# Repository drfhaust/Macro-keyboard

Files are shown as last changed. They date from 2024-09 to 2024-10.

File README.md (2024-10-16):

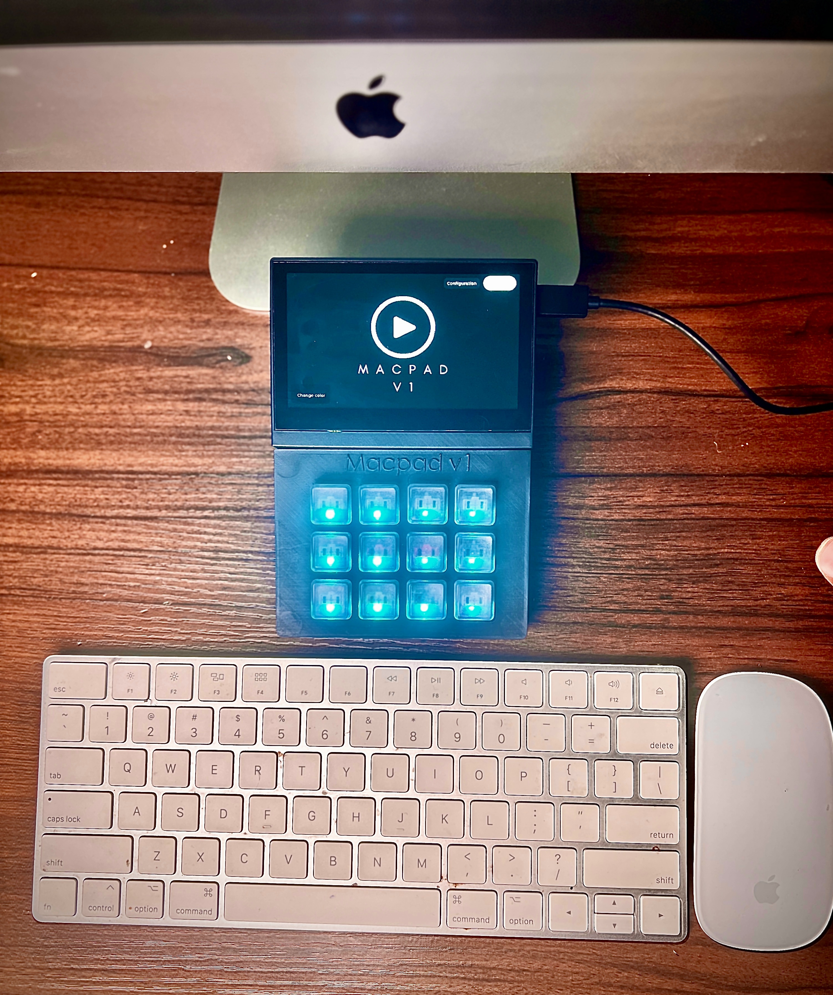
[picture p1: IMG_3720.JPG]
image of the macro keyboard

# Macro Keyboard

**Macro Keyboard with ESP32-S3**

This repository contains the design and code for building a custom macro keyboard powered by the ESP32-S3 microcontroller.

## Overview

- **Design**: A macro keyboard with customizable keys and LEDs for different functionalities.
- **Microcontroller**: Powered by the ESP32-S3 with a built-in touch screen and additional hardware components.
- **Customization**: Supports custom key mappings and macros via a JSON configuration.
- **Hardware Design**: The keyboard's hardware is modular, making it adaptable for various input needs.

## Hardware Specifications

- **Microcontroller**: ESP32-S3 with built-in wireless connectivity.
- **Key Components**: Uses Cherry MX-compatible key switches.
- **LEDs**: Individually addressable RGB LEDs for customizable lighting.
- **Screen**: Touch-enabled screen for additional control and feedback.
- **Battery**: Supports external power, and can be adapted for battery-powered use.
- **Charging**: USB Type-C port for charging and data transfer.
- **Connection**: Supports both wired and wireless communication with a host device.

## Software Features

- **Macro Management**: The macros can be configured through the `button.json` file, where each button is assigned a specific action or macro.
- **LED Control**: RGB LEDs can be customized for each button based on the configuration.
- **Key Mapping**: Easily programmable for various applications, from simple shortcuts to complex multi-step macros.
- **Python Integration**: Python scripts are provided to manage macro configurations and interface with the hardware.

## Power Details

- **Power Input**: Powered through USB Type-C or battery.
- **Power Consumption**: Optimized for low power consumption during idle states.

## Repository Structure

- **Arduino code**: Contains the LVGL porting for the ESP32-S3 along with the Arduino source code for the project.
  - `lvgl_Porting`: Core source files for integrating LVGL (LittlevGL) with the ESP32-S3.
  
- **Macro keyboard**: Includes hardware designs, PCB schematics, and component configurations.
  - `GERBER`: Files for manufacturing the PCB.
  - `custom components`: KiCad components for custom parts used in the keyboard.
  - `backups`: Backup files for the PCB designs.

- **python code**: Python scripts to manage macros and configure button functionalities.
  - `macro_manager_v4.py`: Python script for managing the macro functions of the keyboard.
  
- **solidwork 3d**: 3D models of the keyboard parts, including key switches and case designs.
  
- **button.json**: Configuration file where button mappings and LED colors are stored.

## Getting Started

1. **Clone this repository**:
   ```bash
   git clone <repository-url>
   ```

2. **Hardware Setup**: 
   - Flash the ESP32-S3 with the code in `Arduino code/lvgl_Porting`.
   - Assemble the PCB and components according to the schematics in the `Macro keyboard` folder.

3. **Software Setup**:
   - Install the required Python libraries by running:
     ```bash
     pip install -r requirements.txt
     ```

4. **Macro Management**:
   - Configure macros by editing `button.json`.
   - Run the macro manager script to apply your changes:
     ```bash
     python python code/v4/macro_manager_v4.py
     ```

## Contributing

Please read the contribution guidelines before making any changes.

## License

This project is licensed under the MIT License.

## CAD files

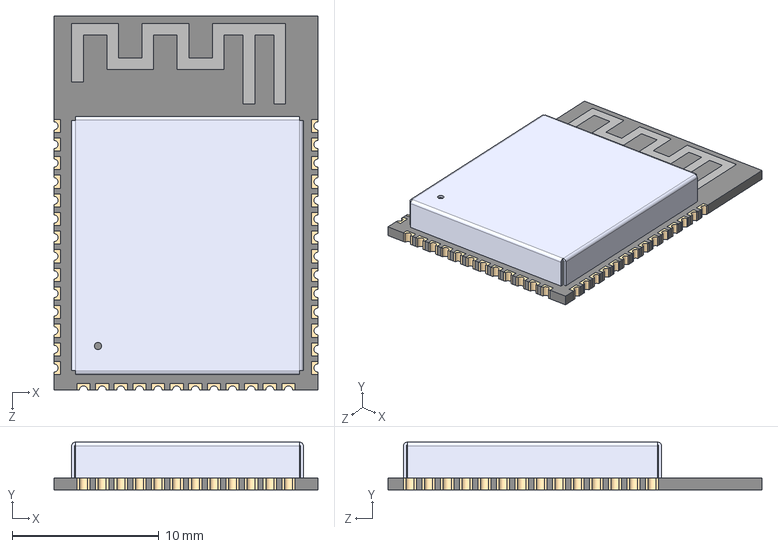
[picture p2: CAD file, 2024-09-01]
macro mech keyboard/custom components/ESP32-S3-WROOM-1-N8R8.step
18.0 x 3.25 x 25.5 mm

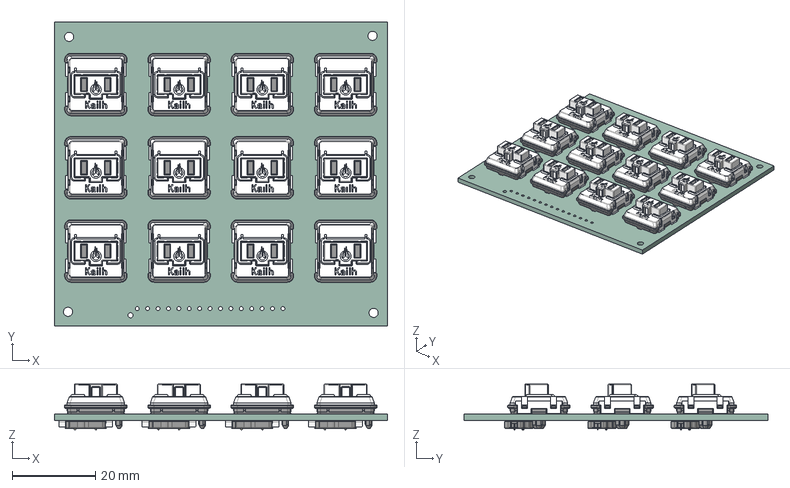
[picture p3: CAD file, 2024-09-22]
macro mech keyboard/Macro keyboard.step
80.0 x 73.1 x 11.0 mm
C_0603_1608Metric x 12
kailh CPG135001D03 x 12
PG1350 x 12
Macro keyboard_PCB

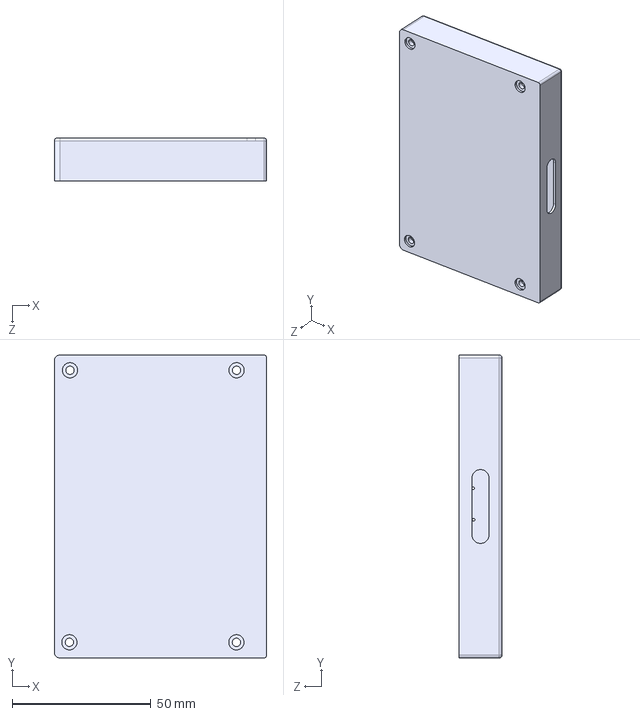
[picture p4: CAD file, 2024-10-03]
solidwork 3d/SCREEN BEZEL.STEP
76.5 x 109.2 x 15.5 mm

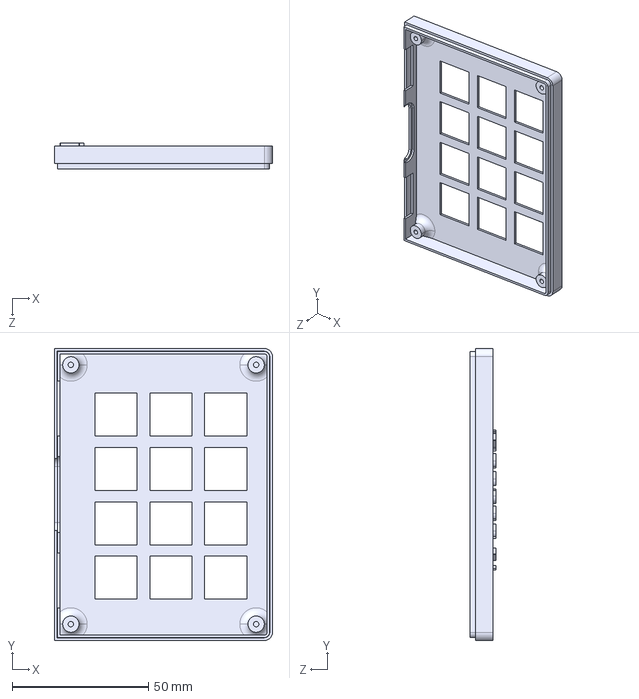
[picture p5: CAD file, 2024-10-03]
solidwork 3d/key top.STEP
80.0 x 107.2 x 9.50 mm

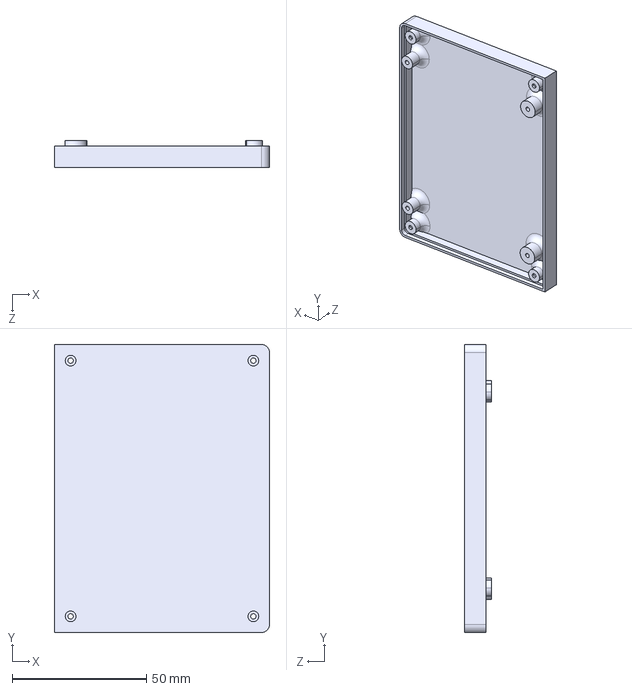
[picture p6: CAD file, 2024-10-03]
solidwork 3d/key btm.STEP
80.0 x 107.2 x 10.0 mm

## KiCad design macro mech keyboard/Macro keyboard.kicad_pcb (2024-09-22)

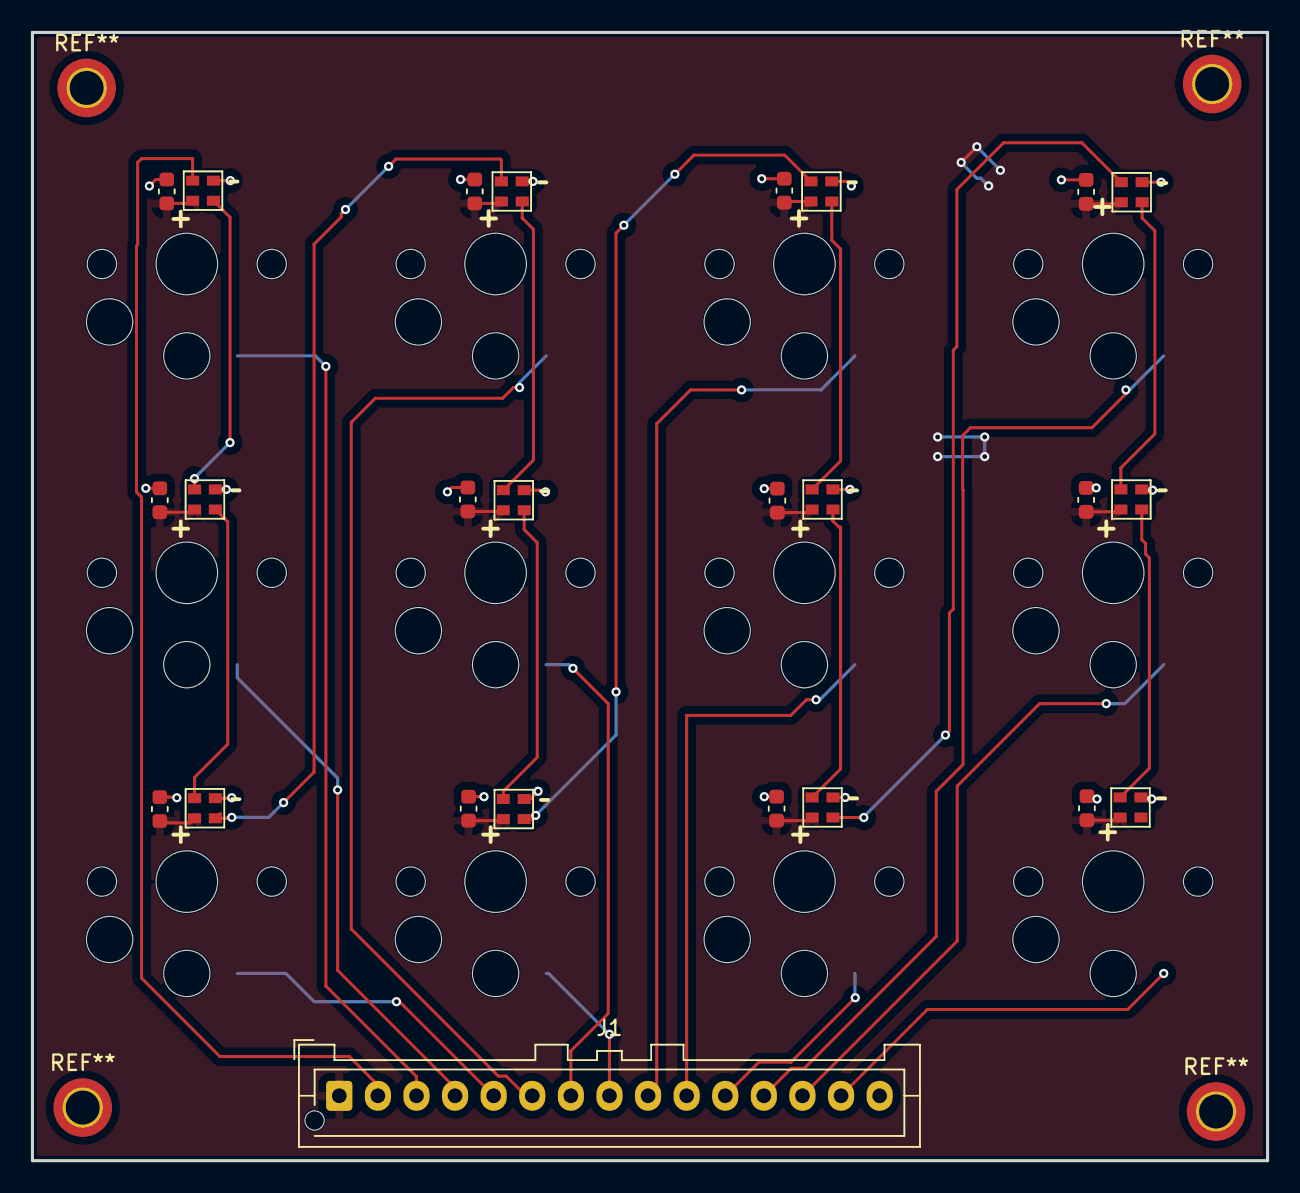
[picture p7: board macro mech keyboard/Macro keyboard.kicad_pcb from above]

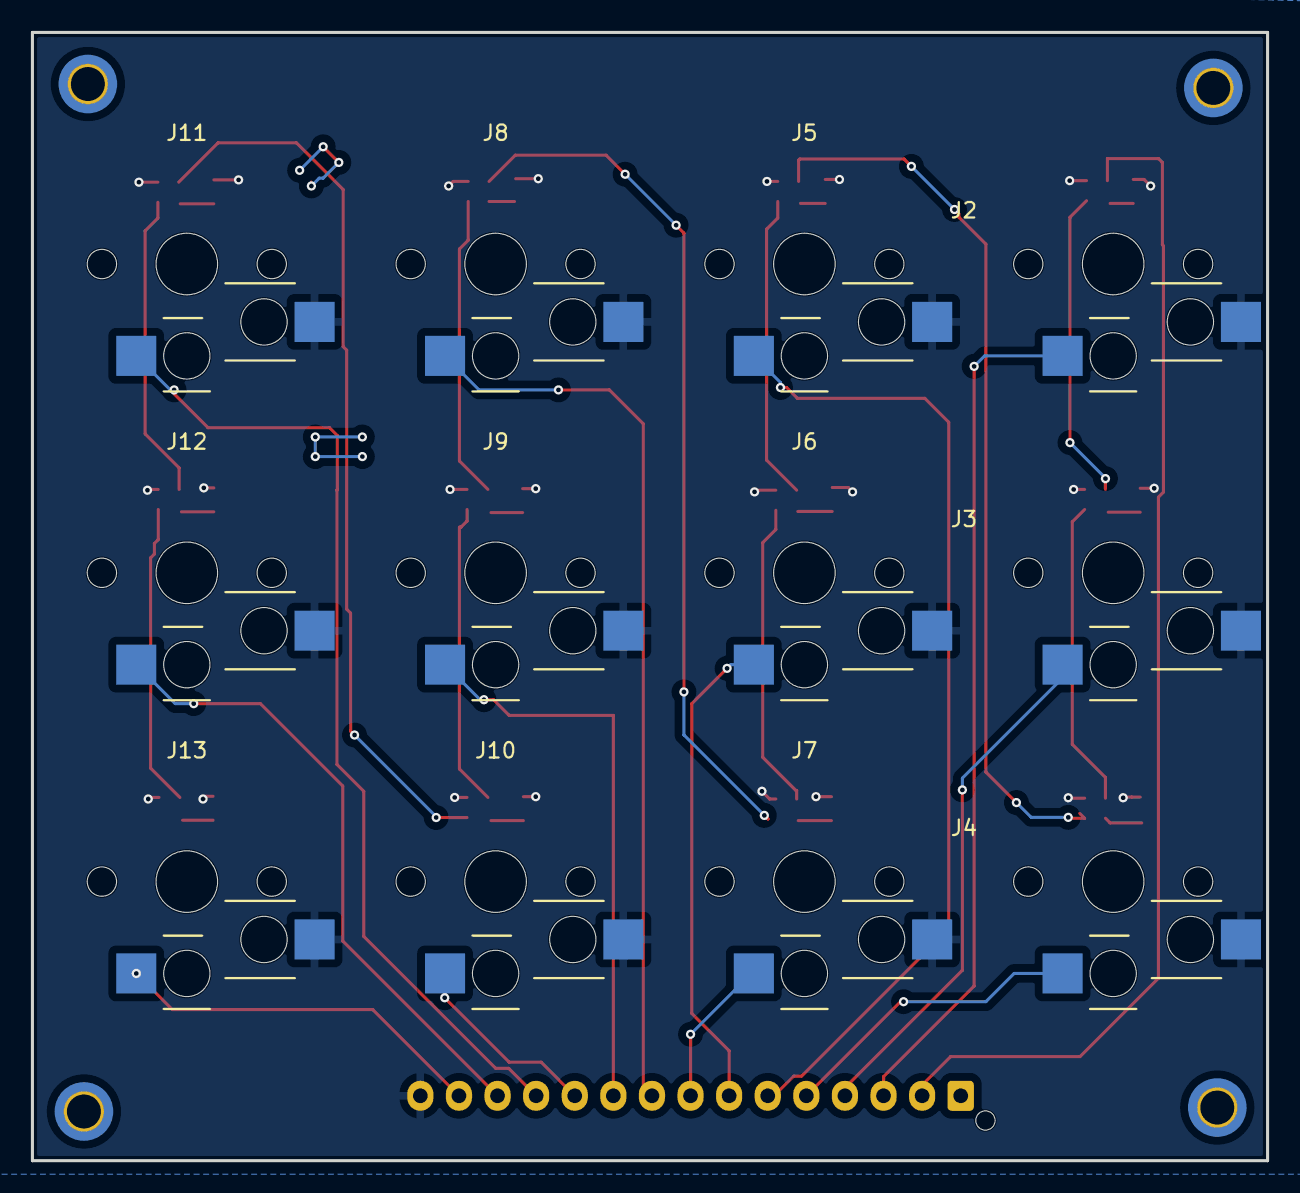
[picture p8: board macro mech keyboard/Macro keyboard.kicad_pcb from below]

Board: 2 copper layers, 80.0 x 73.1 mm, 37 parts (12 on the bottom side), 26 nets.

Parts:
C13, C14, C15, C16, C17, C18, C19, C20, C21, C22, C23, C24: 100n; C_0603_1608Metric
D2, D3, D4, D5, D6, D7, D8, D9, D10, D11, D12, D13: RGB; LED_SMD_XINGLIGHT_XL-2020RGBC-WS2812B
J1: Conn_01x15_Pin; JST_XA_B15B-XASK-1-A_1x15_P2.50mm_Vertical
J2, J3, J4, J5, J6, J7, J8, J9, J10, J11, J12, J13: CPG135001S30; Connector_Keyswitch_Socket_KAILH_CPG135001S30

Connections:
+3.3V: C13.1, C14.1, C15.1, C16.1, C17.1, C18.1, C19.1, C20.1, C21.1, C22.1, C23.1, C24.1, D2.4 (vdd), D3.4 (vdd), D4.4 (vdd), D5.4 (vdd), D6.4 (vdd), D7.4 (vdd), D8.4 (vdd), D9.4 (vdd), D10.4 (vdd), D11.4 (vdd), D12.4 (vdd), D13.4 (vdd), J1.1
/BUTTON1: J1.3, J2.1
/BUTTON2: J1.4, J3.1
/BUTTON3: J1.5, J4.1
/BUTTON4: J1.6, J5.1
/BUTTON5: J1.7, J6.1
/BUTTON6: J1.8, J7.1
/BUTTON7: J1.9, J8.1
/BUTTON8: J1.10, J9.1
/BUTTON9: J1.11, J10.1
/BUTTON10: J1.12, J11.1
/BUTTON11: J1.13, J12.1
/BUTTON12: J1.14, J13.1
/RGBLED: D2.3 (di), J1.2
/RGBc: D7.1 (do), D8.3 (di)
GND: C13.2, C14.2, C15.2, C16.2, C17.2, C18.2, C19.2, C20.2, C21.2, C22.2, C23.2, C24.2, D2.2 (gnd), D3.2 (gnd), D4.2 (gnd), D5.2 (gnd), D6.2 (gnd), D7.2 (gnd), D8.2 (gnd), D9.2 (gnd), D10.2 (gnd), D11.2 (gnd), D12.2 (gnd), D13.2 (gnd), J1.15, J2.2, J3.2, J4.2, J5.2, J6.2, J7.2, J8.2, J9.2, J10.2, J11.2, J12.2, J13.2
unnamed: D2.1 (do), D3.3 (di)
unnamed: D3.1 (do), D4.3 (di)
unnamed: D4.1 (do), D5.3 (di)
unnamed: D5.1 (do), D6.3 (di)
unnamed: D6.1 (do), D7.3 (di)
unnamed: D8.1 (do), D9.3 (di)
unnamed: D9.1 (do), D10.3 (di)
unnamed: D10.1 (do), D11.3 (di)
unnamed: D11.1 (do), D12.3 (di)
unnamed: D12.1 (do), D13.3 (di)

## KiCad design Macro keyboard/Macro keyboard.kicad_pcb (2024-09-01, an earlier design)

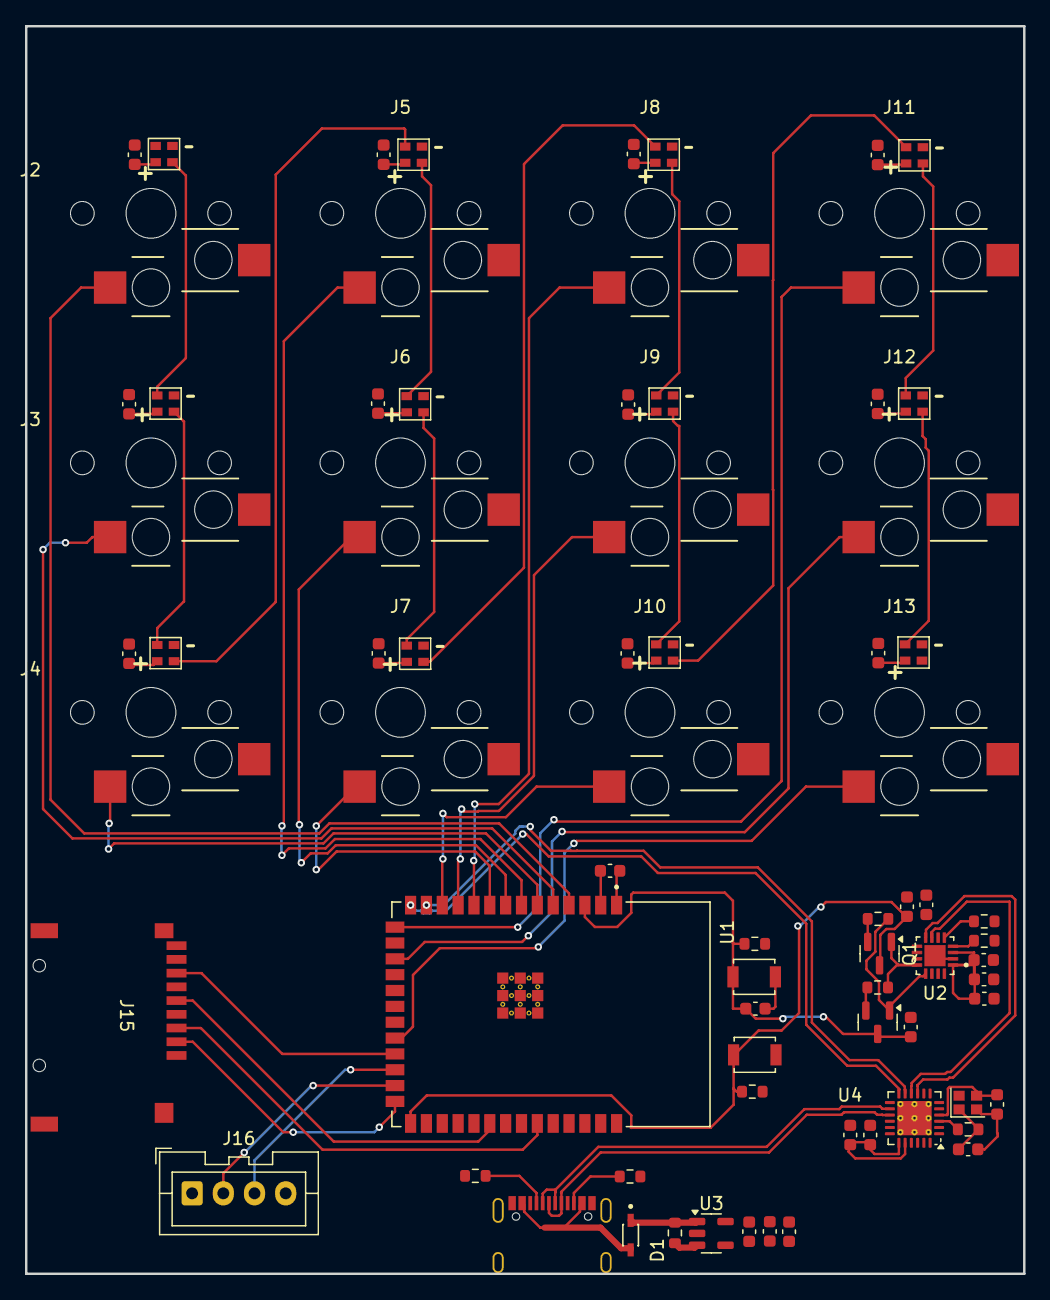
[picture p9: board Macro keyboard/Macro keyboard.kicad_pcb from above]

Board: 2 copper layers, 80.0 x 100.0 mm, 74 parts (0 on the bottom side), 56 nets.

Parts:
C1, C27: 1uf; C_0603_1608Metric
C2: 4.7uf; C_0603_1608Metric
C3, C4, C5: 100nf; C_0603_1608Metric
C6, C12, C25, C26: 10uf; C_0603_1608Metric
C7, C8, C11: 1UF; C_0603_1608Metric
C9, C10: 15pf; C_0603_1608Metric
C13, C14, C15, C16, C17, C18, C19, C20, C21, C22, C23, C24: 100n; C_0603_1608Metric
D1: B5819WS-TP; SOD2512X115N
D2, D3, D4, D5, D6, D7, D8, D9, D10, D11, D12, D13: RGB; LED_SMD_XINGLIGHT_XL-2020RGBC-WS2812B
J1: MC-126D-DG10; Connector_USB-C_HANBO-ELECTRONIC_MC-126D-DG10
J2, J3, J4, J5, J6, J7, J8, J9, J10, J11, J12, J13: CPG135001S30; Connector_Keyswitch_Socket_KAILH_CPG135001S30
J15: GT-TF003-H0185-02; Connector_MicroSD_G-SWITCH_GT-TF003-H0185-02
J16: Conn_01x04_Pin; JST_XA_B04B-XASK-1_1x04_P2.50mm_Vertical
Q1, Q2: S8050; SOT-23
R1, R2: 12k; R_0603_1608Metric
R3: 100K; R_0603_1608Metric
R5, R6: 0R; R_0603_1608Metric
R7, R8: 5k1; R_0603_1608Metric
R10: 1k; R_0603_1608Metric
R11, R12: 10k; R_0603_1608Metric
SW1, SW2: SW_Push; SW_SPST_B3U-1000P
U1: ESP32-S3-WROOM-1-N8R8; XCVR_ESP32S3WROOM1N8R8
U2: CH343P; QFN50P300X300X80-17N
U3: AP2112K-3.3; SOT-23-5
U4: QFN-24-1EP_4x4mm_P0.5mm_EP2.75x2.75mm_ThermalVias
Y1: Crystal_GND24; Crystal_SMD_2016-4Pin_2.0x1.6mm

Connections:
+3.3V: C3.1, C4.1, C5.1, C7.1, C8.1, C12.1, C13.1, C14.1, C15.1, C16.1, C17.1, C18.1, C19.1, C20.1, C21.1, C22.1, C23.1, C24.1, C25.1, C26.1, C27.1, D2.4 (vdd), D3.4 (vdd), D4.4 (vdd), D5.4 (vdd), D6.4 (vdd), D7.4 (vdd), D8.4 (vdd), D9.4 (vdd), D10.4 (vdd), D11.4 (vdd), D12.4 (vdd), D13.4 (vdd), J16.4, R11.2, R12.2, U1.2 (3V3), U2.1 (VIO), U2.3 (VDD5), U2.6 (V3), U3.5 (VOUT), U4.19 (V5), U4.20 (VDD33)
+5V: C6.1, D1.C, R3.1, U2.9 (VBUS), U3.1 (VIN)
/BUTTON1: J2.1, U1.4 (IO4)
/BUTTON2: J3.1, U1.5 (IO5)
/BUTTON3: J4.1, U1.6 (IO6)
/BUTTON4: J5.1, U1.7 (IO7)
/BUTTON5: J6.1, U1.8 (IO15)
/BUTTON6: J7.1, U1.9 (IO16)
/BUTTON7: J8.1, U1.10 (IO17)
/BUTTON8: J9.1, U1.11 (IO18)
/BUTTON9: J10.1, U1.12 (IO8)
/BUTTON10: J11.1, U1.15 (IO3)
/BUTTON11: J12.1, U1.17 (IO9)
/BUTTON12: J13.1, U1.22 (IO14)
/D+: J1.A6 (D+), J1.B6 (D+), U4.15 (DPU)
/D-: J1.A7 (D-), J1.B7 (D-), U4.14 (DMU)
/DTR: Q1.1 (E), R1.2, U2.12 (DTR)
/MISO: J15.7 (DAT0), U1.23 (IO21)
/MOSI: J15.3 (CMD), U1.35 (IO42)
/RGBLED: D2.3 (di), U1.31 (IO38)
/RGBc: D7.1 (do), D8.3 (di)
/RTS: Q2.1 (E), R2.2, U2.13 (RTS)
/SCK: J15.5 (CLK), U1.32 (IO39)
/SD/CS: J15.2 (DAT3/CD), U1.26 (IO45)
/espD+: U1.14 (IO20), U4.12 (DP1)
/espD-: U1.13 (IO19), U4.11 (DM1)
/uartD+: U2.7 (UD+), U4.10 (DP2)
/uartD-: U2.8 (UD-), U4.9 (DM2)
EN: C2.1, C11.1, Q2.3 (C), R11.1, SW1.2, U1.3 (EN)
GND: C1.1, C2.2, C3.2, C4.2, C5.2, C6.2, C7.2, C8.2, C9.2, C10.2, C11.2, C12.2, C13.2, C14.2, C15.2, C16.2, C17.2, C18.2, C19.2, C20.2, C21.2, C22.2, C23.2, C24.2, C25.2, C26.2, C27.2, D2.2 (gnd), D3.2 (gnd), D4.2 (gnd), D5.2 (gnd), D6.2 (gnd), D7.2 (gnd), D8.2 (gnd), D9.2 (gnd), D10.2 (gnd), D11.2 (gnd), D12.2 (gnd), D13.2 (gnd), J1.A1 (GND), J1.A12 (GND), J1.B1 (GND), J1.B12 (GND), J1.S1 (SHIELD), J2.2, J3.2, J4.2, J5.2, J6.2, J7.2, J8.2, J9.2, J10.2, J11.2, J12.2, J13.2, J15.6 (VSS), J15.10 (SHIELD), J16.1, R7.1, R8.2, SW1.1, SW2.1, U1.1 (GND), U1.40 (GND), U1.41_1 (GND), U1.41_2 (GND), U1.41_3 (GND), U1.41_4 (GND), U1.41_5 (GND), U1.41_6 (GND), U1.41_7 (GND), U1.41_8 (GND), U1.41_9 (GND), U2.2 (GND), U2.17 (GND), U3.2 (GND), U4.25 (GND), Y1.2, Y1.4
Io0: C1.2, Q1.3 (C), R12.1, SW2.2, U1.27 (IO0)
unnamed: C9.1, R10.2, Y1.1
unnamed: D1.A, J1.A4 (VBUS), J1.A9 (VBUS), J1.B4 (VBUS), J1.B9 (VBUS)
unnamed: D2.1 (do), D3.3 (di)
unnamed: D3.1 (do), D4.3 (di)
unnamed: D4.1 (do), D5.3 (di)
unnamed: D5.1 (do), D6.3 (di)
unnamed: D6.1 (do), D7.3 (di)
unnamed: D8.1 (do), D9.3 (di)
unnamed: D9.1 (do), D10.3 (di)
unnamed: D10.1 (do), D11.3 (di)
unnamed: D11.1 (do), D12.3 (di)
unnamed: D12.1 (do), D13.3 (di)
unnamed: J1.A5 (CC1), R7.2
unnamed: J1.B5 (CC2), R8.1
unnamed: J16.2, U1.25 (IO48)
unnamed: J16.3, U1.24 (IO47)
unnamed: Q1.2 (B), R2.1
unnamed: Q2.2 (B), R1.1
unnamed: R5.1, U2.5 (RXD)
unnamed: R6.2, U2.4 (TXD)
unnamed: R3.2, U3.3 (EN)
unnamed: C10.1, U4.4 (XI), Y1.3
unnamed: R10.1, U4.3 (XO)
RXD: R6.1, U1.36 (RXD0)
TXD: R5.2, U1.37 (TXD0)

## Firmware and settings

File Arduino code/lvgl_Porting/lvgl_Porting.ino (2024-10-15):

#include <Arduino.h>
#include <ESP_Panel_Library.h>
#include <ESP_IOExpander_Library.h>
#include <ui.h>
#include <lvgl.h>
#include "lvgl_port_v8.h"
#include "USB.h"
#include "USBHIDKeyboard.h"
#include <WiFi.h>              //Built-in
#include <ESP32WebServer.h>    //https://github.com/Pedroalbuquerque/ESP32WebServer download and place in your Libraries folder
#include <ESPmDNS.h>
#include <ArduinoJson.h>
#include "CSS.h" //Includes headers of the web and de style file
#include "FS.h"
#include "SD.h"
#include "SPI.h"
#include "PCF8575.h"  // https://github.com/xreef/PCF8575_library


void button1Pressed(lv_event_t * e);
void button2Pressed(lv_event_t * e);
void button3Pressed(lv_event_t * e);
void button4Pressed(lv_event_t * e);
void button5Pressed(lv_event_t * e);
void button6Pressed(lv_event_t * e);
void button7Pressed(lv_event_t * e);
void button8Pressed(lv_event_t * e);
void button9pressed(lv_event_t * e);
void button10Pressed(lv_event_t * e);
void button11Pressed(lv_event_t * e);
void button12Pressed(lv_event_t * e);
void wifiSwitchToggle(lv_event_t * e);
void colorChange(lv_event_t * e);
char buttonModifiers[12][20];
char buttonValues[12][200];  // Assuming values might be longer
int colors[][3] = {
    {255, 0, 0},   // Red
    {0, 255, 0},   // Green
    {0, 0, 255},   // Blue
    {255, 255, 0}, // Yellow
    {0, 255, 255}, // Cyan
    {255, 0, 255}, // Magenta
    {192, 192, 192}, // Silver
    {128, 128, 128}, // Gray
    {0, 128, 0},   // Dark Green
    {128, 0, 0},   // Maroon
    {128, 0, 128}, // Purple
    {0, 128, 128}, // Teal
    {0, 0, 128},   // Navy
    {255, 165, 0}, // Orange
    {255, 192, 203} // Pink
};

int colorIndex = 0; // Global variable to keep track of the current color
// Extend IO Pin define
#define TP_RST 1
#define LCD_BL 2
#define LCD_RST 3
#define SD_CS 4
#define USB_SEL 5

// Extend IO Pin define
#define TP_RST 1
#define LCD_BL 2
#define LCD_RST 3
#define SD_CS 4
#define USB_SEL 5
USBHIDKeyboard Keyboard;
const int buttonPin = 0;  // input pin for pushbutton
#define RXD2 15
#define TXD2 16
const int slaveConnectionPin = 6;  // GPIO pin on Master to detect Slave connection
bool isSlaveConnected = false;     // Tracks whether the slave is connected

int buttonState = 0;  // Store received button states
#define SD_MOSI 11
#define SD_CLK  12
#define SD_MISO 13
#define SD_SS -1
// I2C Pin define
#define I2C_MASTER_NUM I2C_NUM_0
#define I2C_MASTER_SDA_IO 8
#define I2C_MASTER_SCL_IO 9
ESP32WebServer server(80);
#define servername "keyboard" //Define the name to your server... 
bool   SD_present = false; //Controls if the SD card is present or not
char nwMode = 0;


void handleModifier(const char* modifier, const char* value) {
  if (strcmp(modifier, "paste") == 0) {
    if (value != NULL && strlen(value) > 0) {
      // If a value is provided, simulate typing the value (custom paste)
      Keyboard.println(value);  // Simulate typing the provided value
    } else {
      // If no value is provided, perform native paste (CTRL + V)
      Keyboard.press(KEY_LEFT_CTRL);
      Keyboard.press('v');
      delay(200);  // Small delay to ensure key press is registered
      Keyboard.releaseAll();  // Release the keys
    }

  } else if (strcmp(modifier, "copy") == 0) {
    // Handle native copy action (CTRL + C)
    Keyboard.press(KEY_LEFT_CTRL);
    Keyboard.press('c');
    delay(200);  // Small delay to ensure key press is registered
    Keyboard.releaseAll();  // Release the keys

  } else if (strcmp(modifier, "open") == 0) {
    // Use Windows + R to open the Run dialog
    Keyboard.press(KEY_LEFT_GUI);
    Keyboard.press('r');
    delay(200);  // Allow time for the Windows + R to open the Run dialog
    Keyboard.releaseAll();

    delay(100);  // Wait for the Run dialog to appear

    Keyboard.println(value);  // Type the value (path)
    delay(50);

    Keyboard.press(KEY_RETURN);  // Press Enter to execute the command
    delay(100);
    Keyboard.releaseAll();  // Release all keys

  } else if (strcmp(modifier, "screenshot") == 0) {
    // Take a screenshot using Alt + Print Screen
    Keyboard.press(KEY_RIGHT_ALT);
    Keyboard.press(KEY_PRINT_SCREEN);
    delay(200);  // Allow time for the keys to register
    Keyboard.releaseAll();  // Release both keys
  
  } else {
    // Add a fallback for unsupported modifiers
    // Serial.println(modifier);  // Uncomment for debugging
  }
}
  


// Global variable to store the LED color in "R,G,B" format
String ledColorString = "0,0,0";  // Default to black

void readJsonFile(fs::FS &fs, const char *path) {
  // Open the JSON file from the SD card
  File file = fs.open(path);
  if (!file) {
    Serial.println("Failed to open file for reading");
    return;
  }

  // Calculate the size of the file
  size_t size = file.size();
  if (size == 0) {
    Serial.println("File is empty");
    return;
  }

  // Allocate a buffer to store the content of the file
  std::unique_ptr<char[]> buf(new char[size]);

  // Read all the content of the file into the buffer
  file.readBytes(buf.get(), size);

  // Parse the JSON data
  DynamicJsonDocument doc(4096);  // Adjust size based on the JSON complexity
  DeserializationError error = deserializeJson(doc, buf.get());

  if (error) {
    Serial.print("Failed to parse JSON: ");
    Serial.println(error.f_str());
    return;
  }

  // Iterate over all button key-value pairs in the JSON object
  for (JsonPair kv : doc.as<JsonObject>()) {
    const char* key = kv.key().c_str();
    JsonObject obj = kv.value().as<JsonObject>();

    // Check if "value", "modifier", and "text" keys exist
    if (obj.containsKey("modifier") && obj.containsKey("value") && obj.containsKey("text")) {
      const char* modifier = obj["modifier"];
      const char* value = obj["value"];
      const char* text = obj["text"];  // Read the 'text' key for the textarea content

      // Store the modifier and value based on the button key
      if (strcmp(key, "button1") == 0) {
        strncpy(buttonModifiers[0], modifier, sizeof(buttonModifiers[0]) - 1);
        strncpy(buttonValues[0], value, sizeof(buttonValues[0]) - 1);
        lv_textarea_set_text(ui_TextArea4, text);  // Update the textarea with the 'text' field
      } else if (strcmp(key, "button2") == 0) {
        strncpy(buttonModifiers[1], modifier, sizeof(buttonModifiers[1]) - 1);
        strncpy(buttonValues[1], value, sizeof(buttonValues[1]) - 1);
        lv_textarea_set_text(ui_TextArea5, text);
      } else if (strcmp(key, "button3") == 0) {
        strncpy(buttonModifiers[2], modifier, sizeof(buttonModifiers[2]) - 1);
        strncpy(buttonValues[2], value, sizeof(buttonValues[2]) - 1);
        lv_textarea_set_text(ui_TextArea6, text);
      } else if (strcmp(key, "button4") == 0) {
        strncpy(buttonModifiers[3], modifier, sizeof(buttonModifiers[3]) - 1);
        strncpy(buttonValues[3], value, sizeof(buttonValues[3]) - 1);
        lv_textarea_set_text(ui_TextArea7, text);
      } else if (strcmp(key, "button5") == 0) {
        strncpy(buttonModifiers[4], modifier, sizeof(buttonModifiers[4]) - 1);
        strncpy(buttonValues[4], value, sizeof(buttonValues[4]) - 1);
        lv_textarea_set_text(ui_TextArea8, text);
      } else if (strcmp(key, "button6") == 0) {
        strncpy(buttonModifiers[5], modifier, sizeof(buttonModifiers[5]) - 1);
        strncpy(buttonValues[5], value, sizeof(buttonValues[5]) - 1);
        lv_textarea_set_text(ui_TextArea9, text);
      } else if (strcmp(key, "button7") == 0) {
        strncpy(buttonModifiers[6], modifier, sizeof(buttonModifiers[6]) - 1);
        strncpy(buttonValues[6], value, sizeof(buttonValues[6]) - 1);
        lv_textarea_set_text(ui_TextArea10, text);
      } else if (strcmp(key, "button8") == 0) {
        strncpy(buttonModifiers[7], modifier, sizeof(buttonModifiers[7]) - 1);
        strncpy(buttonValues[7], value, sizeof(buttonValues[7]) - 1);
        lv_textarea_set_text(ui_TextArea11, text);
      } else if (strcmp(key, "button9") == 0) {
        strncpy(buttonModifiers[8], modifier, sizeof(buttonModifiers[8]) - 1);
        strncpy(buttonValues[8], value, sizeof(buttonValues[8]) - 1);
        lv_textarea_set_text(ui_TextArea12, text);
      } else if (strcmp(key, "button10") == 0) {
        strncpy(buttonModifiers[9], modifier, sizeof(buttonModifiers[9]) - 1);
        strncpy(buttonValues[9], value, sizeof(buttonValues[9]) - 1);
        lv_textarea_set_text(ui_TextArea13, text);
      } else if (strcmp(key, "button11") == 0) {
        strncpy(buttonModifiers[10], modifier, sizeof(buttonModifiers[10]) - 1);
        strncpy(buttonValues[10], value, sizeof(buttonValues[10]) - 1);
        lv_textarea_set_text(ui_TextArea14, text);
      } else if (strcmp(key, "button12") == 0) {
        strncpy(buttonModifiers[11], modifier, sizeof(buttonModifiers[11]) - 1);
        strncpy(buttonValues[11], value, sizeof(buttonValues[11]) - 1);
        lv_textarea_set_text(ui_TextArea15, text);
      }
    }
  }

  // Handle the LED color part
  if (doc.containsKey("ledColor")) {
    JsonArray ledColorArray = doc["ledColor"];

    if (ledColorArray.size() == 3) {  // Ensure it has three values
      int red = ledColorArray[0];
      int green = ledColorArray[1];
      int blue = ledColorArray[2];

      // Store the RGB values in a global string in "R,G,B" format
      ledColorString = String(red) + "," + String(green) + "," + String(blue);

      // Print the RGB values to the Serial port
      Serial.println("LED Color: " + ledColorString);
    } else {
      Serial.println("Invalid LED color format");
    }
  }

  file.close();
}



void startWebServer() {
  WiFi.softAP("KeyboardAP", "password"); //Network and password for the access point genereted by ESP32

  //Set your preferred server name, if you use "mcserver" the address would be http://mcserver.local/
  if (!MDNS.begin(servername))
  {
    Serial.println(F("Error setting up MDNS responder!"));
    ESP.restart();
  }
  server.on("/",         SD_dir);
  server.on("/upload",   File_Upload);
  server.on("/fupload",  HTTP_POST, []() {
    server.send(200);
  }, handleFileUpload);

  server.begin();
  nwMode = 1;
  Serial.println("HTTP server started");
}

void endProgram() {
  WiFi.disconnect();
  WiFi.mode(WIFI_OFF);
   ESP.restart();
  //Serial.println("WiFi and server deinitialized. Program ended.");
  nwMode = 0;

  
}

 




void setup()
{
Serial.begin(9600);
  pinMode(GPIO_INPUT_IO_4, OUTPUT); 
    pinMode(slaveConnectionPin, INPUT_PULLUP);  // Set the GPIO 6 pin to input mode

  Keyboard.begin();
  USB.begin();
//Serial.println("Initialize IO expander");


  /* Initialize IO expander */
  ESP_IOExpander *expander = new ESP_IOExpander_CH422G((i2c_port_t)I2C_MASTER_NUM, ESP_IO_EXPANDER_I2C_CH422G_ADDRESS_000, I2C_MASTER_SCL_IO, I2C_MASTER_SDA_IO);
  // ESP_IOExpander *expander = new ESP_IOExpander_CH422G(I2C_MASTER_NUM, ESP_IO_EXPANDER_I2C_CH422G_ADDRESS_000);
  expander->init();
  expander->begin();
  expander->multiPinMode(TP_RST | LCD_BL | LCD_RST | SD_CS | USB_SEL, OUTPUT);
  expander->multiDigitalWrite(TP_RST | LCD_BL | LCD_RST, HIGH);
  delay(100);
  expander->multiDigitalWrite(TP_RST | LCD_RST, LOW);
  delay(100);
  digitalWrite(GPIO_INPUT_IO_4, LOW);
  delay(100);
  expander->multiDigitalWrite(TP_RST | LCD_RST, HIGH);
  delay(200);
 expander->digitalWrite(SD_CS, LOW);
  expander->digitalWrite(USB_SEL, LOW);
  SPI.setHwCs(false);
  SPI.begin(SD_CLK, SD_MISO, SD_MOSI, SD_SS);
  if (!SD.begin()) {
    //Serial.println("Card Mount Failed");
    
    SD_present = false;
    return;
  }
  uint8_t cardType = SD.cardType();

  if (cardType == CARD_NONE) {
    //Serial.println("No SD card attached");
    return;
  }
  else
  {
    //Serial.println(F("Card initialised... file access enabled..."));
   
    SD_present = true;
  } 

  // Serial.println("Initialize panel device");
  ESP_Panel *panel = new ESP_Panel();
  panel->init();
#if LVGL_PORT_AVOID_TEAR
  // When avoid tearing function is enabled, configure the RGB bus according to the LVGL configuration
  ESP_PanelBus_RGB *rgb_bus = static_cast<ESP_PanelBus_RGB *>(panel->getLcd()->getBus());
  rgb_bus->configRgbFrameBufferNumber(LVGL_PORT_DISP_BUFFER_NUM);
  rgb_bus->configRgbBounceBufferSize(LVGL_PORT_RGB_BOUNCE_BUFFER_SIZE);
#endif
  panel->begin();

  // Serial.println("Initialize LVGL");
  lvgl_port_init(panel->getLcd(), panel->getTouch());
  lvgl_port_lock(-1);
  ui_init();
 /* Release the mutex */
  lvgl_port_unlock();
  lv_label_set_text(ui_Label3, "My updated text");
//String full = String(servername) + ".local";
char full[50];
strcpy(full, servername);    // Copy the servername to 'full'
  strcat(full, ".local");      // Concatenate ".local" to 'full'
 readJsonFile(SD, "/button.json");
  lv_textarea_set_text(ui_TextArea3, "KeyboardAP");
  lv_textarea_set_text(ui_TextArea2, "password");
 lv_textarea_set_text(ui_TextArea1, full);
}

void loop()
{
delay(1);
if (digitalRead(slaveConnectionPin) == LOW) {
   if (!isSlaveConnected) {
      Serial.println("Slave connected. Initiating communication...");
      // Slave is newly connected, send RGB values
      
      Serial2.begin(9600, SERIAL_8N1, RXD2, TXD2);
      delay(1000);
  Serial2.print(colors[colorIndex][0]);
  Serial2.print(",");
  Serial2.print(colors[colorIndex][1]);
  Serial2.print(",");
  Serial2.println(colors[colorIndex][2]);

      isSlaveConnected = true;  // Update state to indicate that slave is connected
    }

  if (Serial2.available() > 0) {
    int buttonPressed = Serial2.read();  // Read the button number (1 to 12, or 0 for no press)

    // Process the button number
    if (buttonPressed > 0) {
      Serial.print("Button ");
      Serial.print(buttonPressed);
       handleModifier(buttonModifiers[buttonPressed-1], buttonValues[buttonPressed-1]);
      Serial.println(" is pressed.");
    } else {
      Serial.println("No button is pressed.");
    }
  }




   if (Serial.available()) {
    String input = Serial.readStringUntil('\n');  // Read input until newline
    processRGBInput(input);  // Process the input and send the RGB data to the Slave
  }
    }
    else {
    if (isSlaveConnected) {
      // Slave has been disconnected
      Serial.println("Slave disconnected. Resetting communication...");
       Serial2.flush();  // Optional: clear any remaining data in the serial buffer
         Serial2.end();
      isSlaveConnected = false;  // Update state to indicate that slave is disconnected
    }
  }
  
  if (nwMode == 1) {
    server.handleClient(); //Listen for client connections
    //Serial.println("IDLE loop");
  }
}


void processRGBInput(String rgbData) {
  // Ensure the format is correct (e.g., 255,0,0)
  if (rgbData.indexOf(',') != -1 && rgbData.length() > 5) {
    Serial2.print(rgbData + "\n");  // Send the RGB data to the Slave via Serial2
    Serial.print("Sent RGB to Slave: ");
    Serial.println(rgbData);   // Print the sent data for debugging
  } else {
    Serial.println("Invalid RGB format. Please enter in the format R,G,B");
  }


}
void button1Pressed(lv_event_t * e)
{
 handleModifier(buttonModifiers[0], buttonValues[0]);
}

void button2Pressed(lv_event_t * e)
{
 handleModifier(buttonModifiers[1], buttonValues[1]);
}

void button3Pressed(lv_event_t * e)
{
 handleModifier(buttonModifiers[2], buttonValues[2]);  // Corrected index
}

void button4Pressed(lv_event_t * e)
{
 handleModifier(buttonModifiers[3], buttonValues[3]);  // Corrected index
}

void button5Pressed(lv_event_t * e)
{
 handleModifier(buttonModifiers[4], buttonValues[4]);  // Corrected index
}

void button6Pressed(lv_event_t * e)
{
 handleModifier(buttonModifiers[5], buttonValues[5]);  // Corrected index
}

void button7Pressed(lv_event_t * e)
{
 handleModifier(buttonModifiers[6], buttonValues[6]);  // Corrected index
}

void button8Pressed(lv_event_t * e)
{
 handleModifier(buttonModifiers[7], buttonValues[7]);  // Corrected index
}

void button9Pressed(lv_event_t * e)
{
 handleModifier(buttonModifiers[8], buttonValues[8]);  // Corrected index
}

void button10Pressed(lv_event_t * e)
{
 handleModifier(buttonModifiers[9], buttonValues[9]);  // Corrected index
}

void button11Pressed(lv_event_t * e)
{
 handleModifier(buttonModifiers[10], buttonValues[10]);  // Corrected index
}

void button12Pressed(lv_event_t * e)
{
 handleModifier(buttonModifiers[11], buttonValues[11]);  // Corrected index
}

void colorChange(lv_event_t * e)
{Serial.println("pressed");
  // Print the current color in the format "R,G,B"
  Serial2.print(colors[colorIndex][0]);
  Serial2.print(",");
  Serial2.print(colors[colorIndex][1]);
  Serial2.print(",");
  Serial2.println(colors[colorIndex][2]);

  // Increment the index to move to the next color
  colorIndex++;

  // If the index reaches the end of the array, reset to 0
  if (colorIndex >= sizeof(colors) / sizeof(colors[0])) {
    colorIndex = 0;
  }
}

void wifiSwitchToggle(lv_event_t * e)
{
 if (lv_obj_has_state(ui_Switch1, LV_STATE_CHECKED)){
   startWebServer();
}
else{
   endProgram();
}
}


/*********  FUNCTIONS  **********/
//Initial page of the server web, list directory and give you the chance of deleting and uploading
void SD_dir()
{
  if (SD_present)
  {
    //Action acording to post, dowload or delete, by MC 2022
    if (server.args() > 0 ) //Arguments were received, ignored if there are not arguments
    {
     Serial.println(server.arg(0));

      String Order = server.arg(0);
      Serial.println(Order);

      if (Order.indexOf("download_") >= 0)
      {
        Order.remove(0, 9);
        SD_file_download(Order);
        Serial.println(Order);
      }

      if ((server.arg(0)).indexOf("delete_") >= 0)
      {
        Order.remove(0, 7);
        SD_file_delete(Order);
        Serial.println(Order);
      }
    }

    File root = SD.open("/");
    if (root) {
      root.rewindDirectory();
      SendHTML_Header();
      webpage += F("<table align='center'>");
      webpage += F("<tr><th>Name/Type</th><th style='width:20%'>Type File/Dir</th><th>File Size</th></tr>");
      printDirectory("/", 0);
      webpage += F("</table>");
      SendHTML_Content();
      root.close();
    }
    else
    {
      SendHTML_Header();
      webpage += F("<h3>No Files Found</h3>");
    }
    append_page_footer();
    SendHTML_Content();
    SendHTML_Stop();   //Stop is needed because no content length was sent
  } else ReportSDNotPresent();
}

//Upload a file to the SD
void File_Upload()
{
  append_page_header();
  webpage += F("<h3>Select File to Upload</h3>");
  webpage += F("<FORM action='/fupload' method='post' enctype='multipart/form-data'>");
  webpage += F("<input class='buttons' style='width:25%' type='file' name='fupload' id = 'fupload' value=''>");
  webpage += F("<button class='buttons' style='width:10%' type='submit'>Upload File</button><br><br>");
  webpage += F("<a href='/'>[Back]</a><br><br>");
  append_page_footer();
  server.send(200, "text/html", webpage);
}

//Prints the directory, it is called in void SD_dir()
void printDirectory(const char * dirname, uint8_t levels)
{

  File root = SD.open(dirname);

  if (!root) {
    return;
  }
  if (!root.isDirectory()) {
    return;
  }
  File file = root.openNextFile();

  int i = 0;
  while (file) {
    if (webpage.length() > 1000) {
      SendHTML_Content();
    }
    if (file.isDirectory()) {
      webpage += "<tr><td>" + String(file.isDirectory() ? "Dir" : "File") + "</td><td>" + String(file.name()) + "</td><td></td></tr>";
      printDirectory(file.name(), levels - 1);
    }
    else
    {
      webpage += "<tr><td>" + String(file.name()) + "</td>";
      webpage += "<td>" + String(file.isDirectory() ? "Dir" : "File") + "</td>";
      int bytes = file.size();
      String fsize = "";
      if (bytes < 1024)                     fsize = String(bytes) + " B";
      else if (bytes < (1024 * 1024))        fsize = String(bytes / 1024.0, 3) + " KB";
      else if (bytes < (1024 * 1024 * 1024)) fsize = String(bytes / 1024.0 / 1024.0, 3) + " MB";
      else                                  fsize = String(bytes / 1024.0 / 1024.0 / 1024.0, 3) + " GB";
      webpage += "<td>" + fsize + "</td>";
      webpage += "<td>";
      webpage += F("<FORM action='/' method='post'>");
      webpage += F("<button type='submit' name='download'");
      webpage += F("' value='"); webpage += "download_" + String(file.name()); webpage += F("'>Download</button>");
      webpage += "</td>";
      webpage += "<td>";
      webpage += F("<FORM action='/' method='post'>");
      webpage += F("<button type='submit' name='delete'");
      webpage += F("' value='"); webpage += "delete_" + String(file.name()); webpage += F("'>Delete</button>");
      webpage += "</td>";
      webpage += "</tr>";

    }
    file = root.openNextFile();
    i++;
  }
  file.close();


}

//Download a file from the SD, it is called in void SD_dir()
void SD_file_download(String filename)
{
  if (SD_present)
  {
    File download = SD.open("/" + filename);
    if (download)
    {
      server.sendHeader("Content-Type", "text/text");
      server.sendHeader("Content-Disposition", "attachment; filename=" + filename);
      server.sendHeader("Connection", "close");
      server.streamFile(download, "application/octet-stream");
      download.close();
    } else ReportFileNotPresent("download");
  } else ReportSDNotPresent();
}
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
